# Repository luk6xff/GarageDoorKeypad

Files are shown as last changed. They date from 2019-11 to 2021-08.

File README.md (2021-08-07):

# GarageDoorKeypad

Keypad and Node applications based on STM32F051R8TX uC. Communication between them is done with ISM NRF24L01+ radio modules.

## HARDWARE
* Microcontroller: STM32F051R8TX
* Radio: NRF24L01+
HW schematics for both Keypad and Node available [here](docs/schematics).

## BUILD INSTRUCTIONS
* `STM32CubeIDE ver.1.3.0` with `STM32Cube FW_L0 V1.11.2` is used for development: https://www.st.com/en/development-tools/stm32cubeide.html
* STM32Cube FW_L0 V1.11.2
* Before a first build, please change all the paths `/home/luk6xff/Projects/GarageDoorKeypad/keypad/` and `/home/luk6xff/Projects/GarageDoorKeypad/node/` in files: `.cproject` , `.mxproject` , `.project` for both projects.
* Press `Build Release` button (hammer icon) in IDE to compile a project.
* Press `Run` button (play icon) in IDE to flash a uC.

## Some pics

* Node:
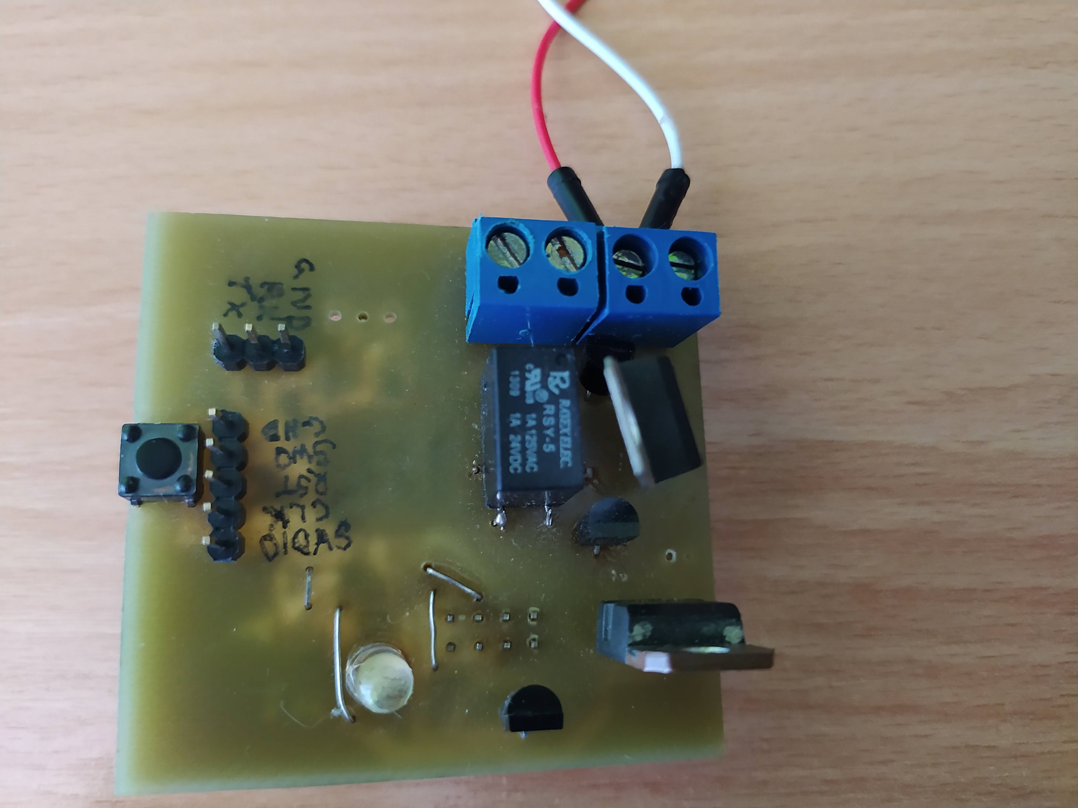
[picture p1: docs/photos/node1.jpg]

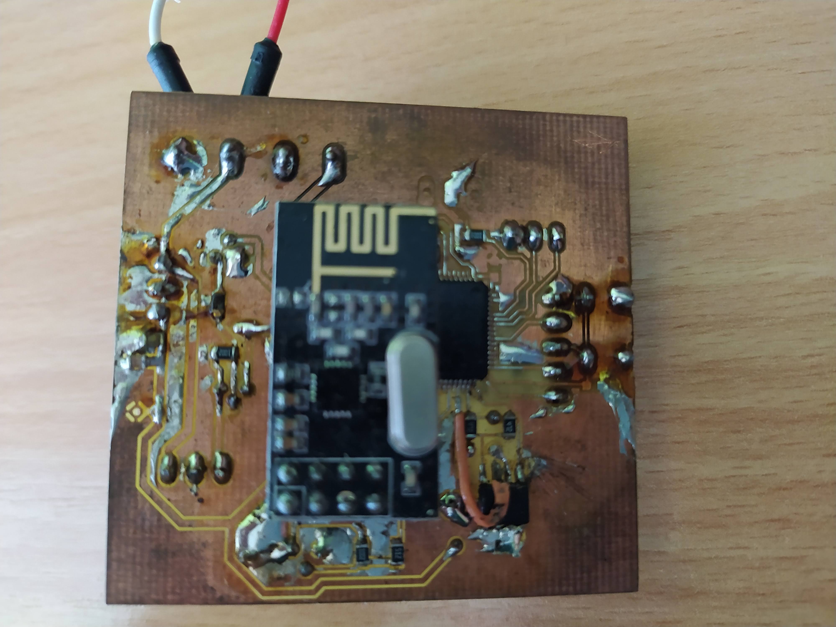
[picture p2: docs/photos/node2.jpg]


* Keypad:
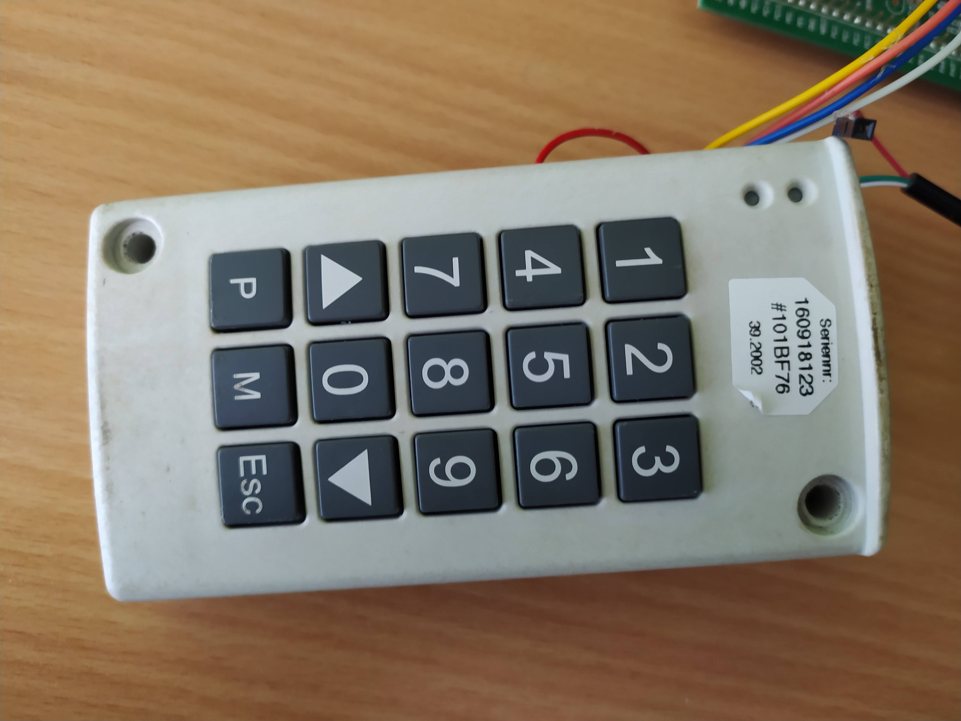
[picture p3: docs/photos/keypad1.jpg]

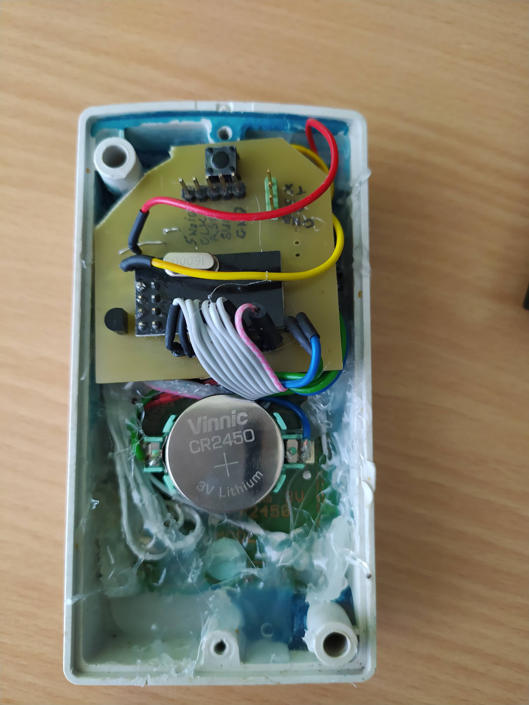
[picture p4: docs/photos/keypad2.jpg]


* Connections:
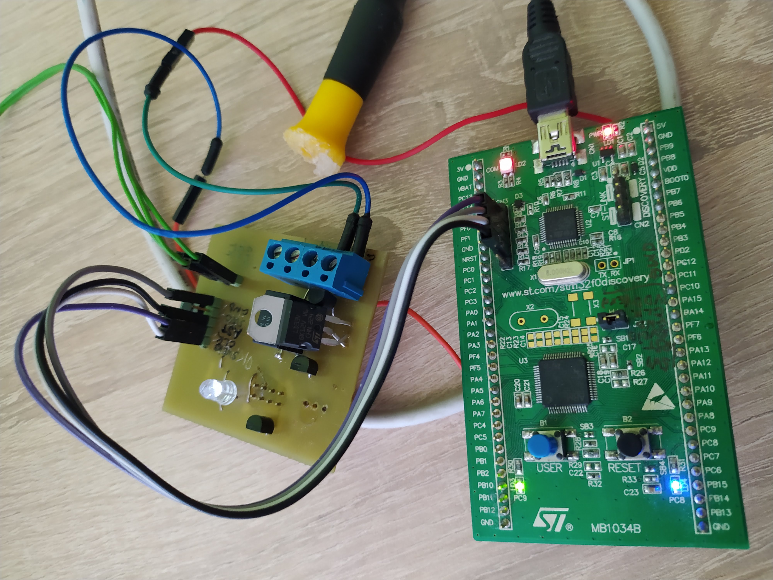
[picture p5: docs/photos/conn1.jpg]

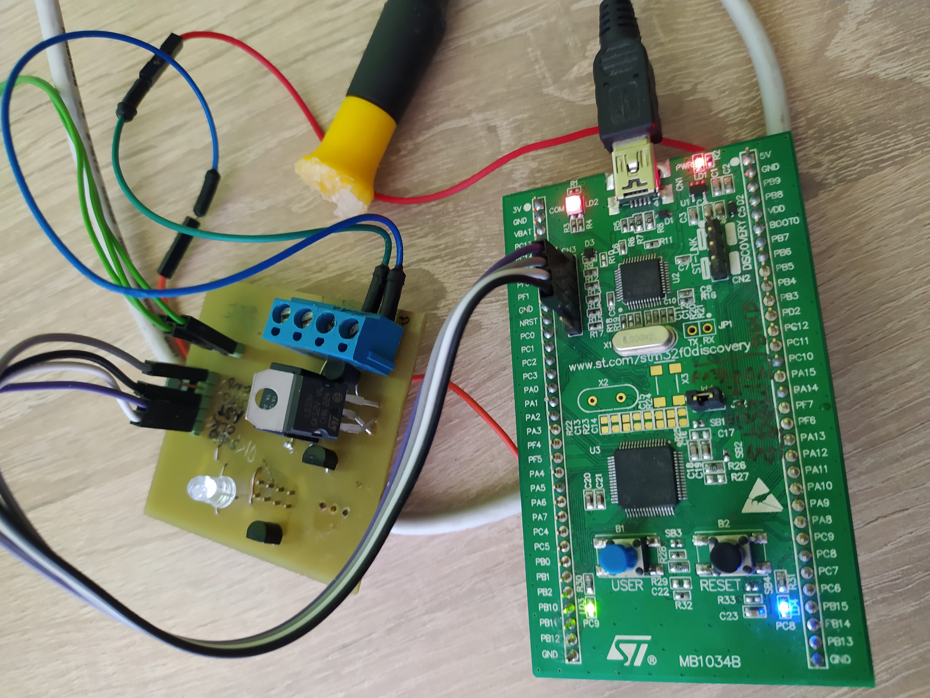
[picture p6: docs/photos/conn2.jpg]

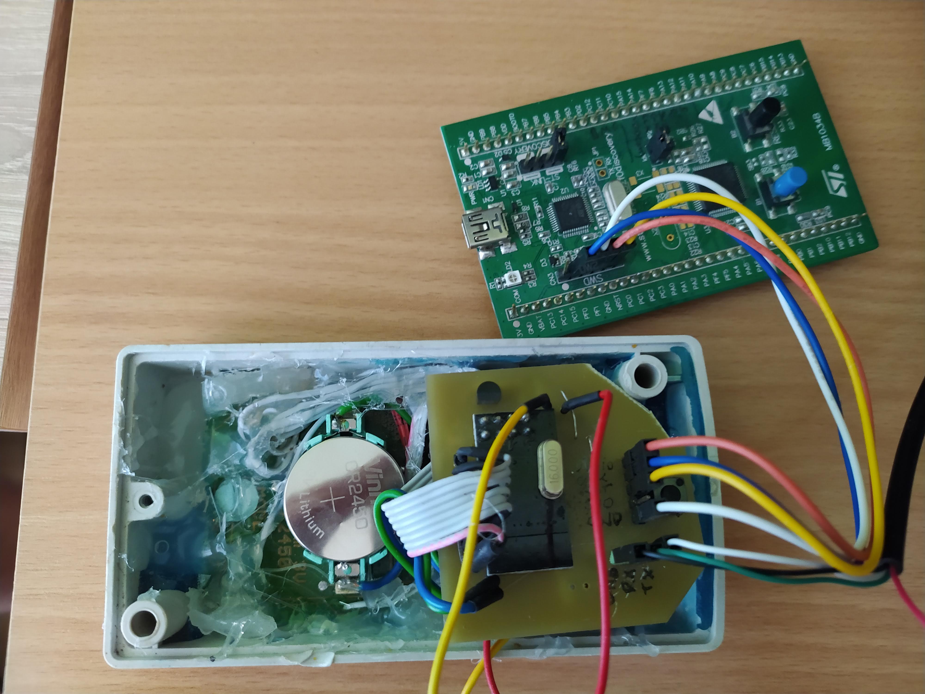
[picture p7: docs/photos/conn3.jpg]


## FAQ
1. To flash SW from CLI:
```sh
~/Tools/STM32/STM32CubeProgrammer/bin/STM32_Programmer_CLI -c port=SWD reset=Hwrst -d ~/Projects/GarageDoorKeypad/.pio/build/disco_f051r8/firmware.elf
```

2. Erase all memory:
```sh
 ~/Tools/STM32/STM32CubeProgrammer/bin/STM32_Programmer_CLI -c port=SWD -e all
```

3. Datasheets to be found [here](docs/datasheets).

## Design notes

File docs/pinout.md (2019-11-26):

# GarageDoorKeypad project pinout
|**uc STM32F051R8T6** |**Peripherals** |
| --- | --- |
| PIN NAME | PIN NAME |
|**_Keypad:_** |
| PA0 | _A_(1,2,3,6) |
| PA1 | _B_(9,4,5,8) |
| PA2 | _C_(0,<,7,>) |
| PA3 | _D_(P,M,ESC) |
| PA4 | _E_(1,9,0,P) |
| PA5 | _F_(3,5,7,ESC) |
| PA6 | _G_(2,4,<,M) |
| PA7 | _H_(6,8,>) |
|**_nRF24L01+:** |
| TR1 (PNP-EMITER) | _GND |
| VCC (3,3V) | VCC |
| PC6 | CE |
| PB12(SPI2_NSS) | CSN |
| PB13(SPI2_SCK) | SCK |
| PB15(SPI2_MOSI) | MOSI|
| PB14(SPI2_MISO) | MISO |
| PC7 | IRQ |
|**_AT24C64D_** |
| GND | A0 |
| GND | A1|
| GND |A2|
| GND |GND |
| PF7(I2C2_SDA)-PullUp 4,7kOhm |SDA |
| PF6(I2C2_SCL)-PullUp 4,7kOhm |SCL|
| PA12-(VCC-disable,GND-enable) |WP |
| VCC (3,3V) |VCC | 
|**_LEDS_** |
| PA11 |GREEN|
| PA10 |RED|
|**_DEBUG_UART_** |
| PB6(USART1_TX) |GOLDPIN_1| 
| PB7(USART1_RX) |GOLDPIN_2|
| GND | GOLDPIN_3 |
|**_ST_LINK_** |
| PA13(SWDIO) |GOLDPIN_1|
| PA14(SWCLK)  |GOLDPIN_2| 
| NRST(ACTIVE_LOW,PullUp-3V) |GOLDPIN_3| 
| PB3 (SWO) |NC|
| GND  |GOLDPIN_5|
|**_POWER_SUPPLY_** |
| 13,1,32,64 (VDDA,VBAT,VDD,VDD) | VCC(3,3)|
| 12,31,63 (VSSA,VSS,VSS) |GND |
|**_TRANSISTORS_** |
|PC8 | TR1 |
|PC9 – FOR RECEIVER ONLY! | _TR2_ |
|  | |
| | | | |

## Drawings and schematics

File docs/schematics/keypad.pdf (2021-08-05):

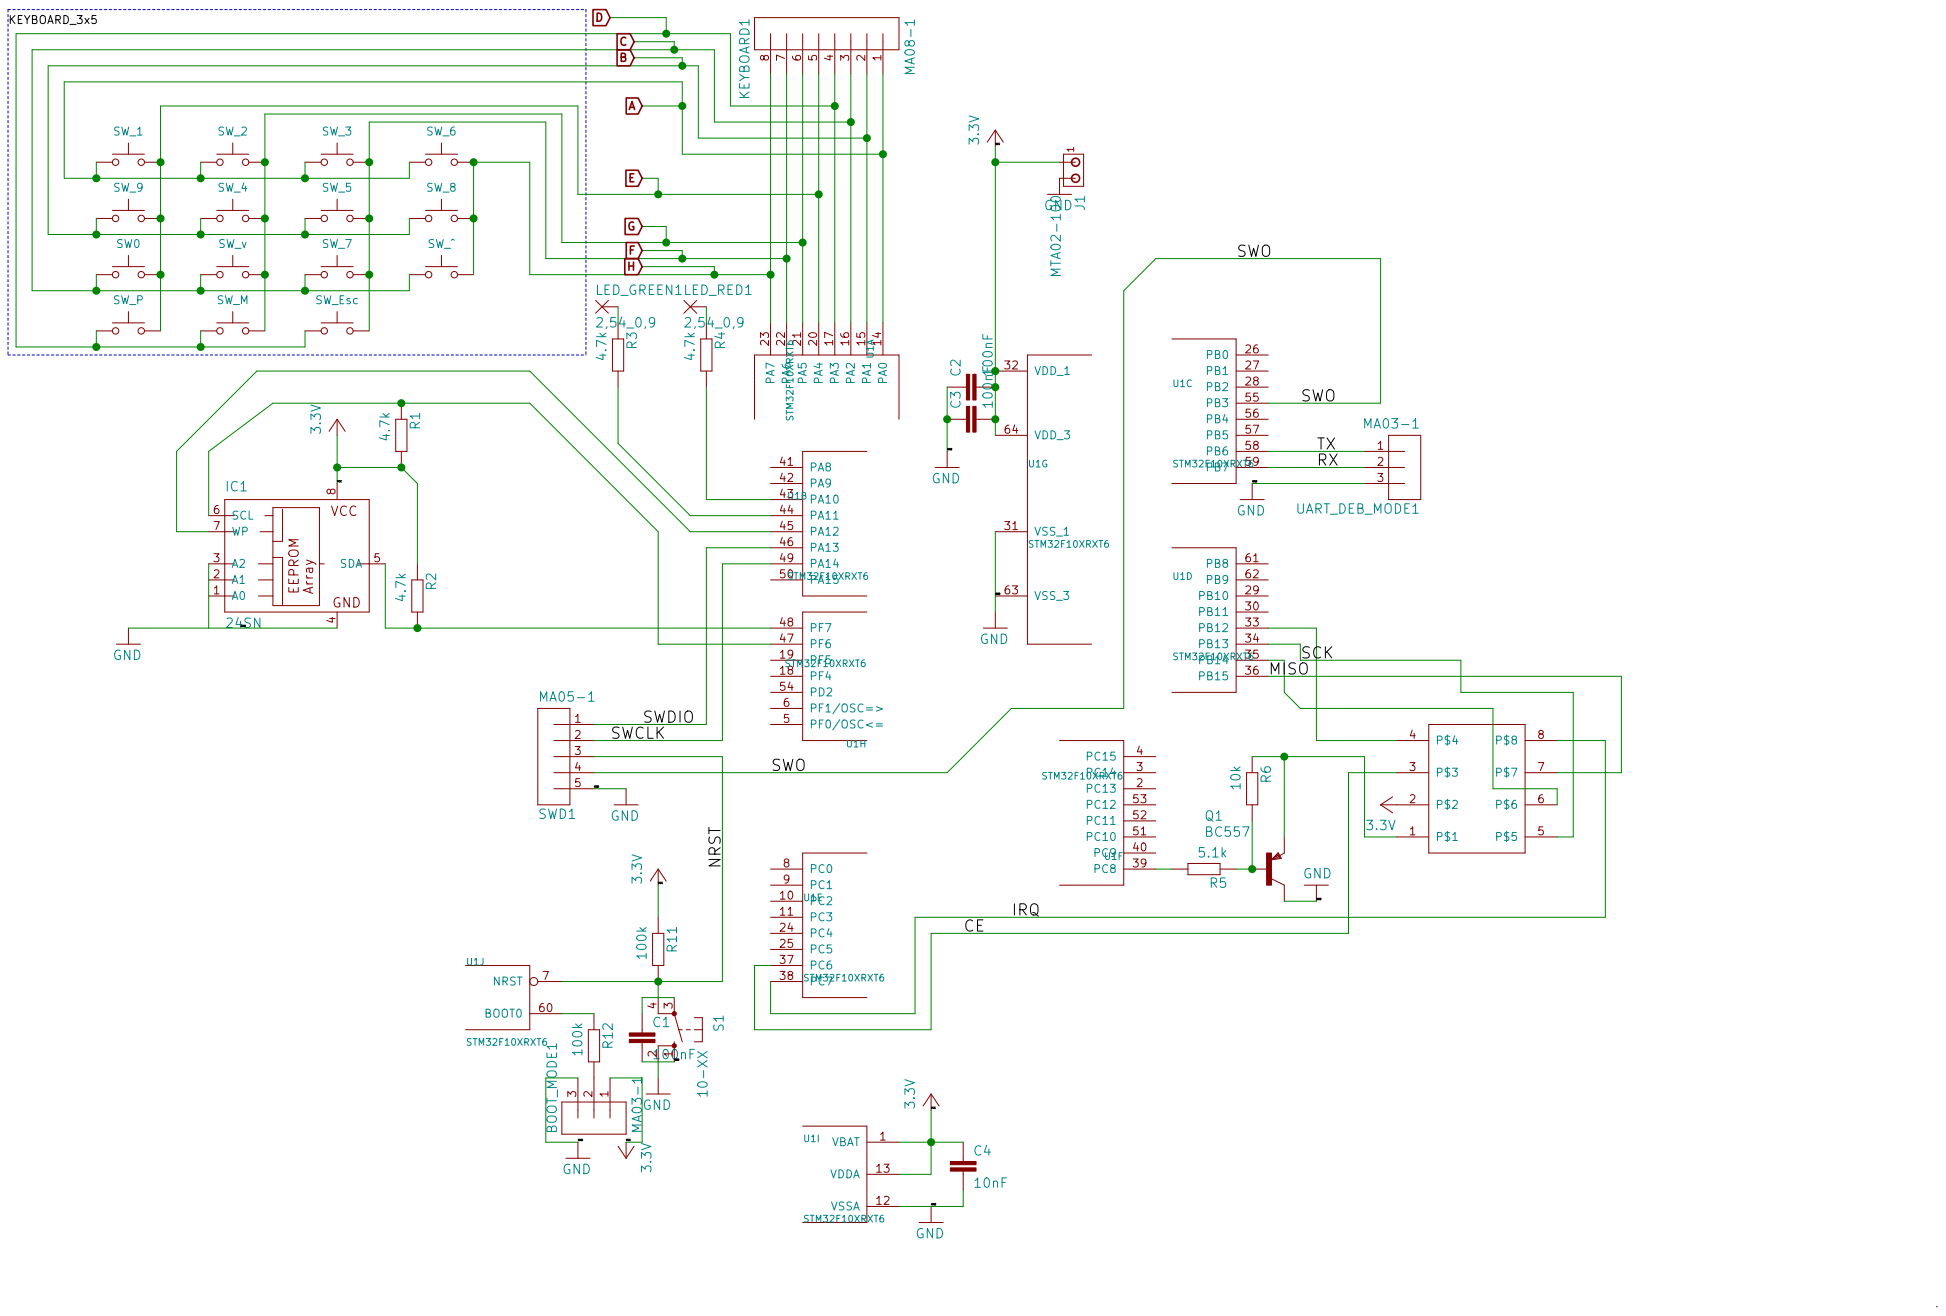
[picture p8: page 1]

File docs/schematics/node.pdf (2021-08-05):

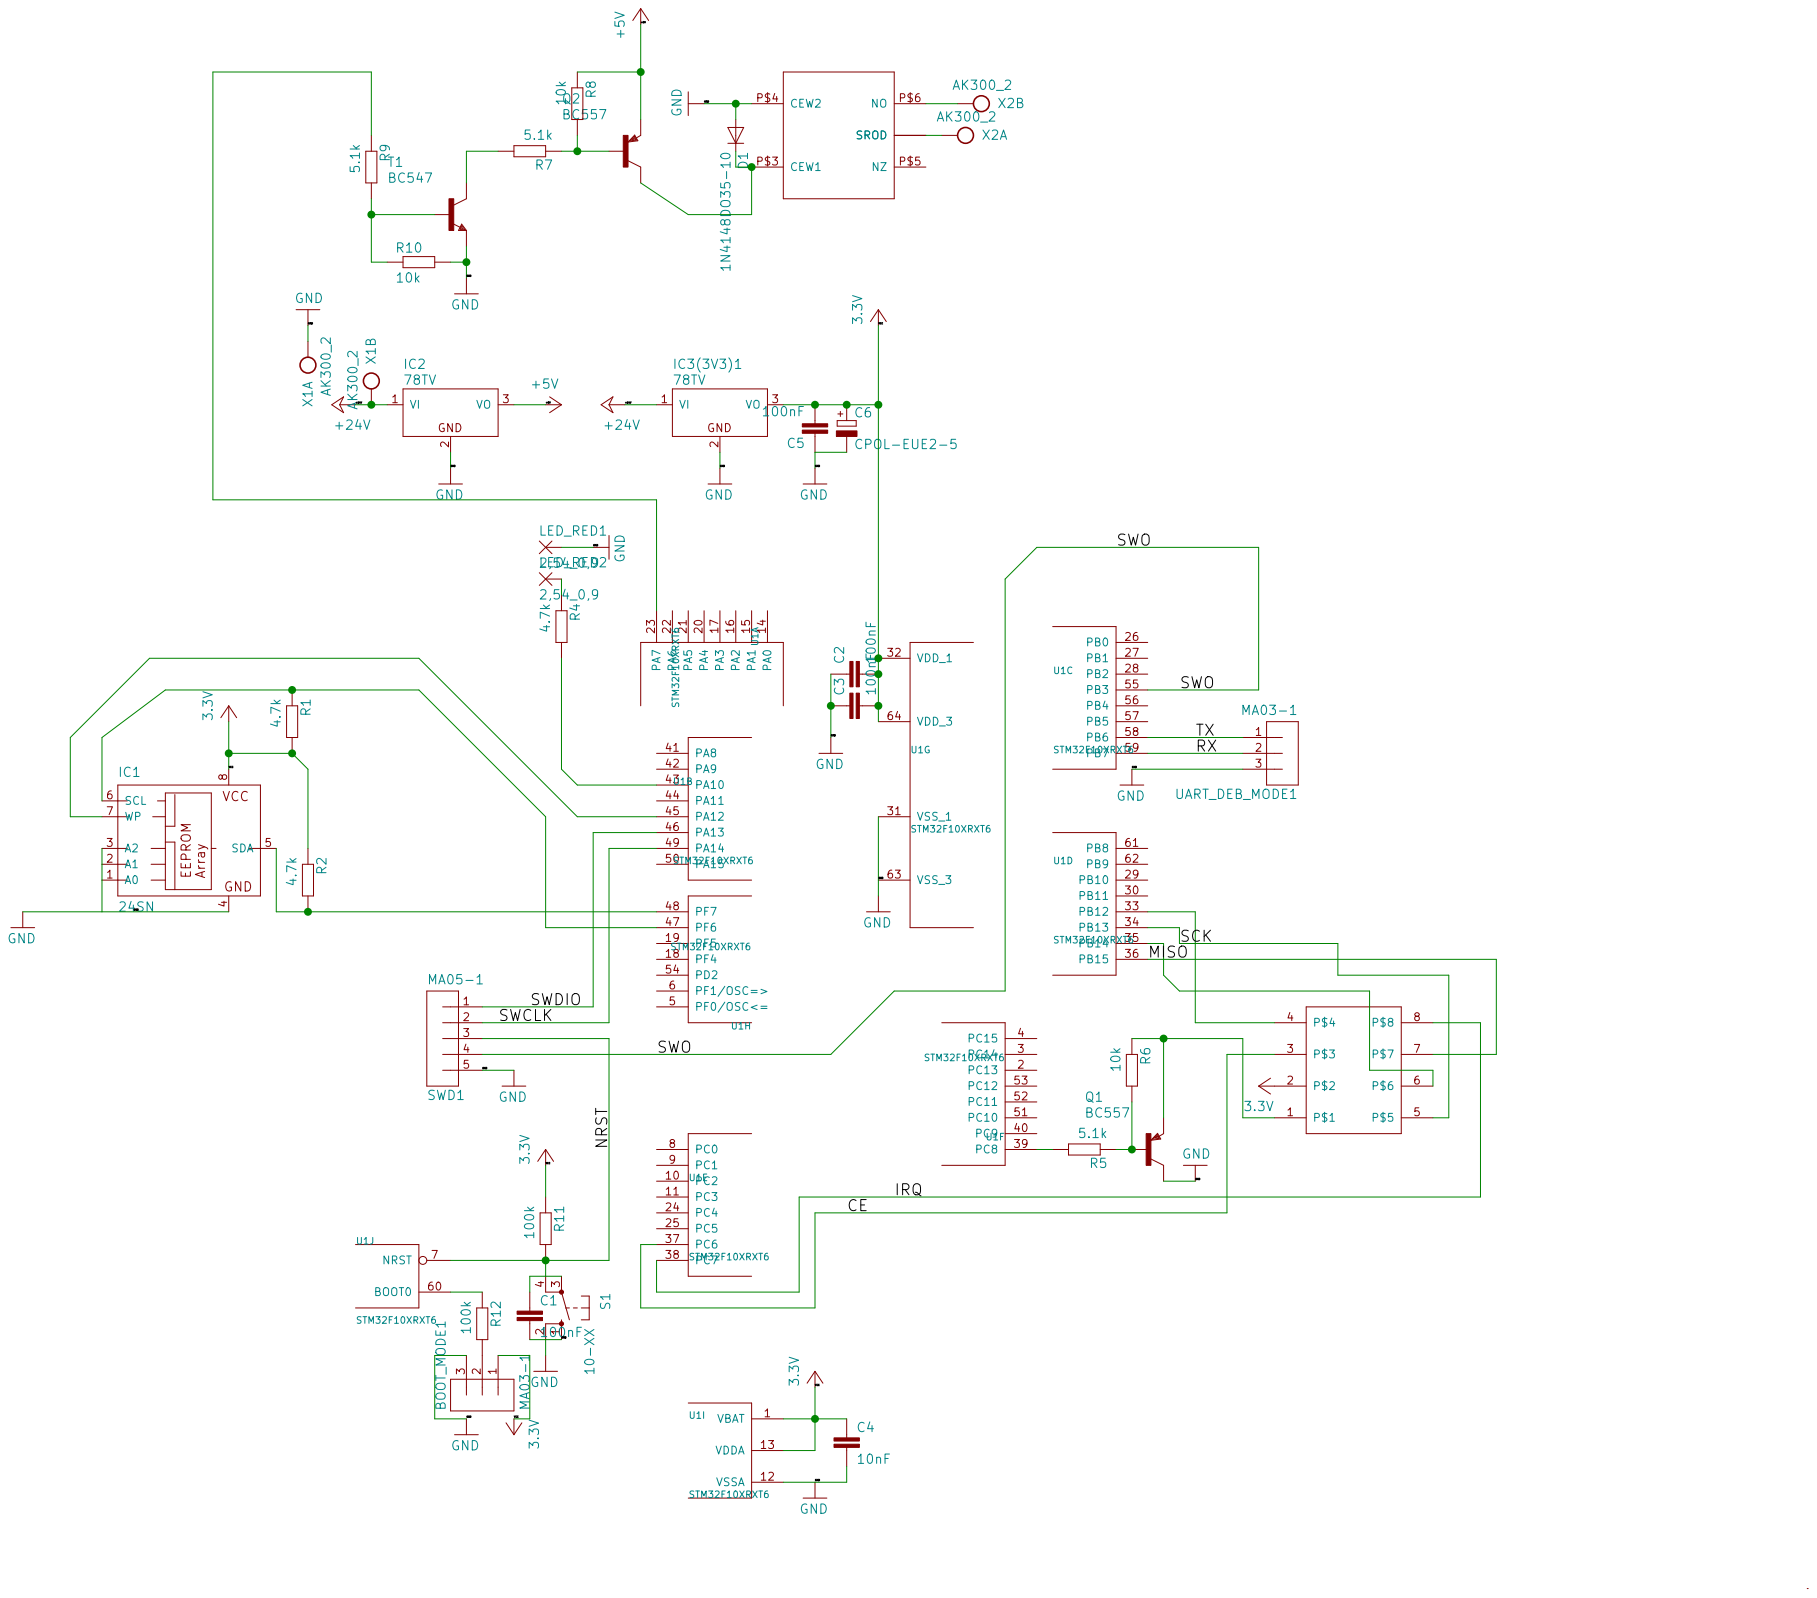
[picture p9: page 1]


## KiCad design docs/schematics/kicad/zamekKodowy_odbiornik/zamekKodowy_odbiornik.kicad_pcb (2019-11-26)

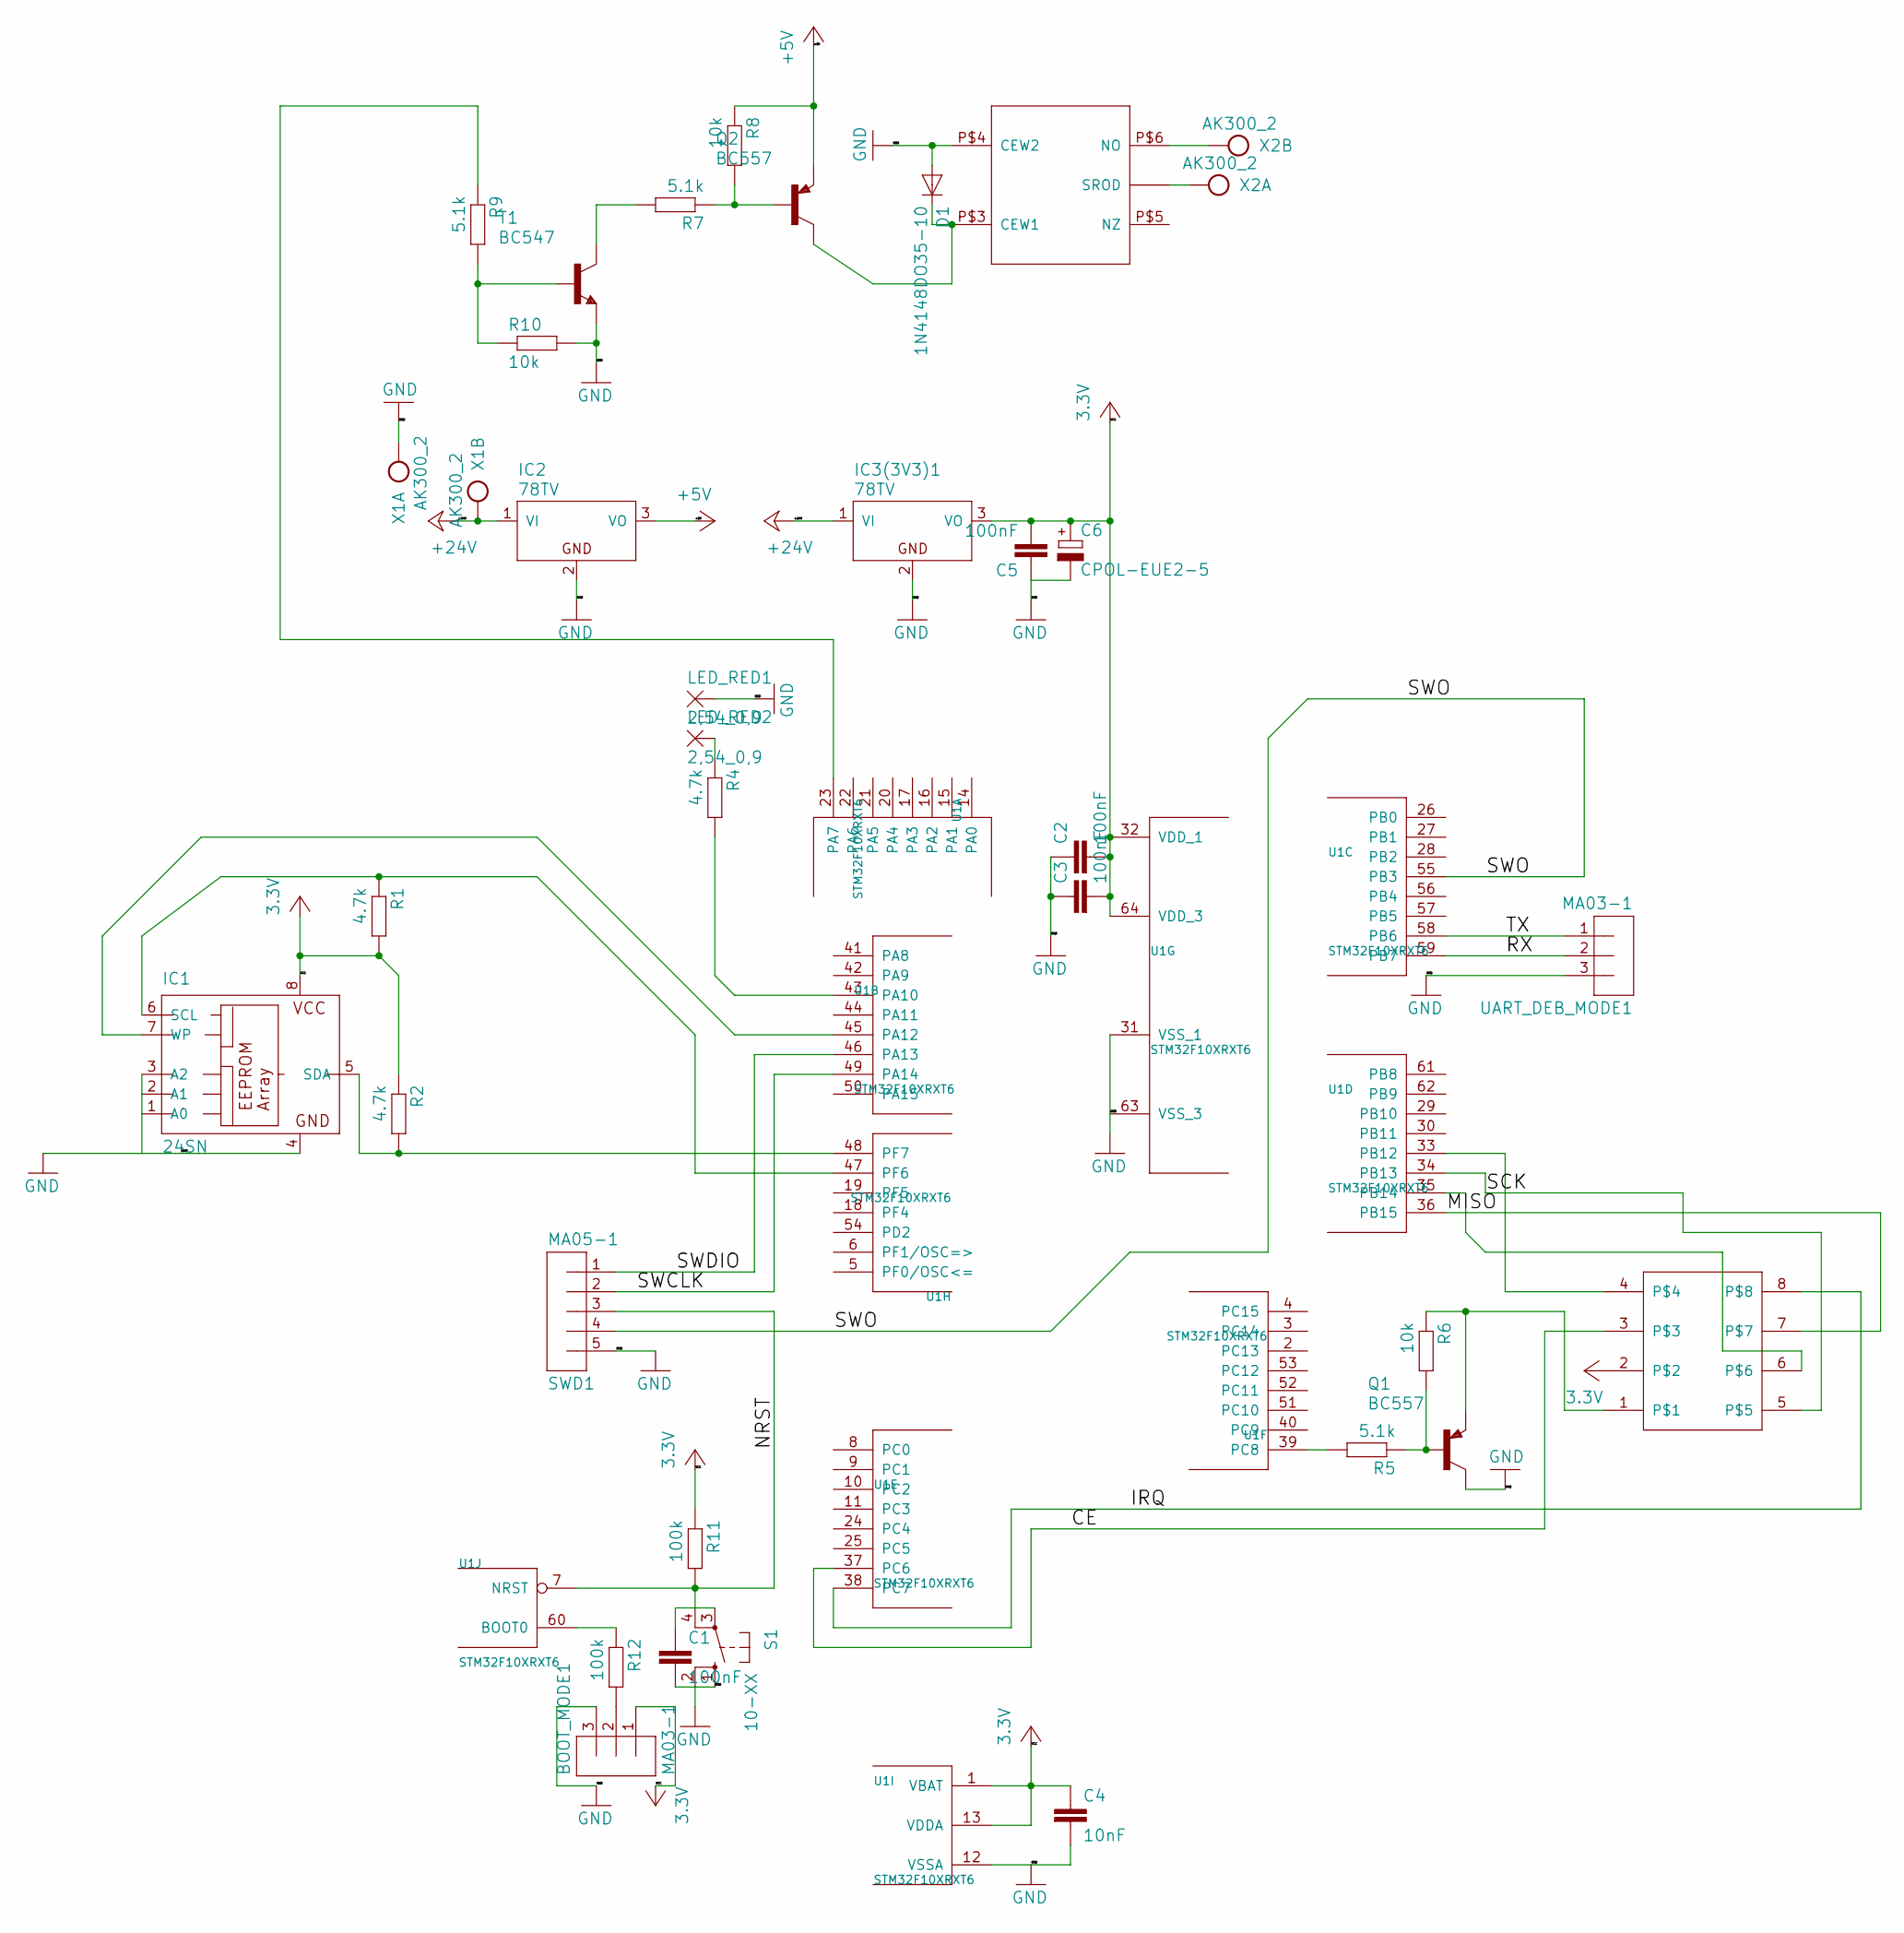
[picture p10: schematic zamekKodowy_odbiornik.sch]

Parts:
BOOT_MODE1: MA03-1
C1, C2, C3, C5: 100nF; C0603
C4: 10nF; C0603
C6: CPOL-EUE2-5; E2-5
CON1: CON10
D1: 1N4148DO35-10; DO35-10
IC1: 24SN; SO-08
IC2, IC3(3V3)1: 78TV; TO220V
LED_RED1, LED_RED2: 2,54_0,9
Q1, Q2: BC557; TO92
R1, R2, R4: 4.7k; R0603
R5, R7, R9: 5.1k; R0603
R6, R8, R10: 10k; R0603
R11, R12: 100k; R0603
S1: 10-XX; B3F-10XX
SWD1: MA05-1
T1: BC547; TO92
U1: STM32F10XRXT6; TQFP64
U$1: PRZEKAZ; FPR
UART_DEB_MODE1: MA03-1
X1, X2: AK300_2

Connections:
+5V: IC2.3 (VO), Q2.1 (E), R8.1
+24V: IC2.1 (VI), IC3(3V3)1.1 (VI), X1.2
/CE: CON1.3, U1.37 (PC6)
/IRQ: CON1.8, U1.38 (PC7)
/MISO: CON1.7, U1.36 (PB15)
/NRST: C1.1, R11.2, S1.3, S1.4 (P1), SWD1.3, U1.7 (NRST)
/RX: U1.59 (PB7), UART_DEB_MODE1.2
/SCK: CON1.5, U1.34 (PB13)
/SWCLK: SWD1.2, U1.49 (PA14)
/SWDIO: SWD1.1, U1.46 (PA13)
/SWO: SWD1.4, U1.55 (PB3)
/TX: U1.58 (PB6), UART_DEB_MODE1.1
GND: BOOT_MODE1.3, C1.2, C2.1, C3.1, C4.2, C5.1, C6.-, D1.A, IC1.1 (A0), IC1.2 (A1), IC1.3 (A2), IC1.4 (GND), IC2.2 (GND), IC3(3V3)1.2 (GND), LED_RED1.1, Q1.3 (C), R10.2, S1.1 (S), S1.2 (S1), SWD1.5, T1.1 (E), U1.12 (VSSA), U1.31 (VSS_1), U1.63 (VSS_3), U$1.P$4 (CEW2), UART_DEB_MODE1.3, X1.1
unnamed: BOOT_MODE1.2, R12.2
unnamed: CON1.1, Q1.1 (E), R6.1
unnamed: CON1.4, U1.33 (PB12)
unnamed: CON1.6, U1.35 (PB14)
unnamed: D1.C, Q2.3 (C), U$1.P$3 (CEW1)
unnamed: IC1.5 (SDA), R2.2, U1.48 (PF7)
unnamed: IC1.6 (SCL), R1.1, U1.47 (PF6)
unnamed: IC1.7 (WP), U1.45 (PA12)
unnamed: LED_RED2.1, R4.1
unnamed: Q1.2 (B), R5.1, R6.2
unnamed: Q2.2 (B), R7.1, R8.2
unnamed: R4.2, U1.43 (PA10)
unnamed: R5.2, U1.39 (PC8)
unnamed: R7.2, T1.3 (C)
unnamed: R9.1, U1.23 (PA7)
unnamed: R9.2, R10.1, T1.2 (B)
unnamed: R12.1, U1.60 (BOOT0)
unnamed: U$1.P$1 (SROD), U$1.P$2 (SROD), X2.1
unnamed: U$1.P$6 (NO), X2.2
VCC: BOOT_MODE1.1, C2.2, C3.2, C4.1, C5.2, C6.+, CON1.2, IC1.8 (VCC), IC3(3V3)1.3 (VO), R1.2, R2.1, R11.1, U1.1 (VBAT), U1.13 (VDDA), U1.32 (VDD_1), U1.64 (VDD_3)

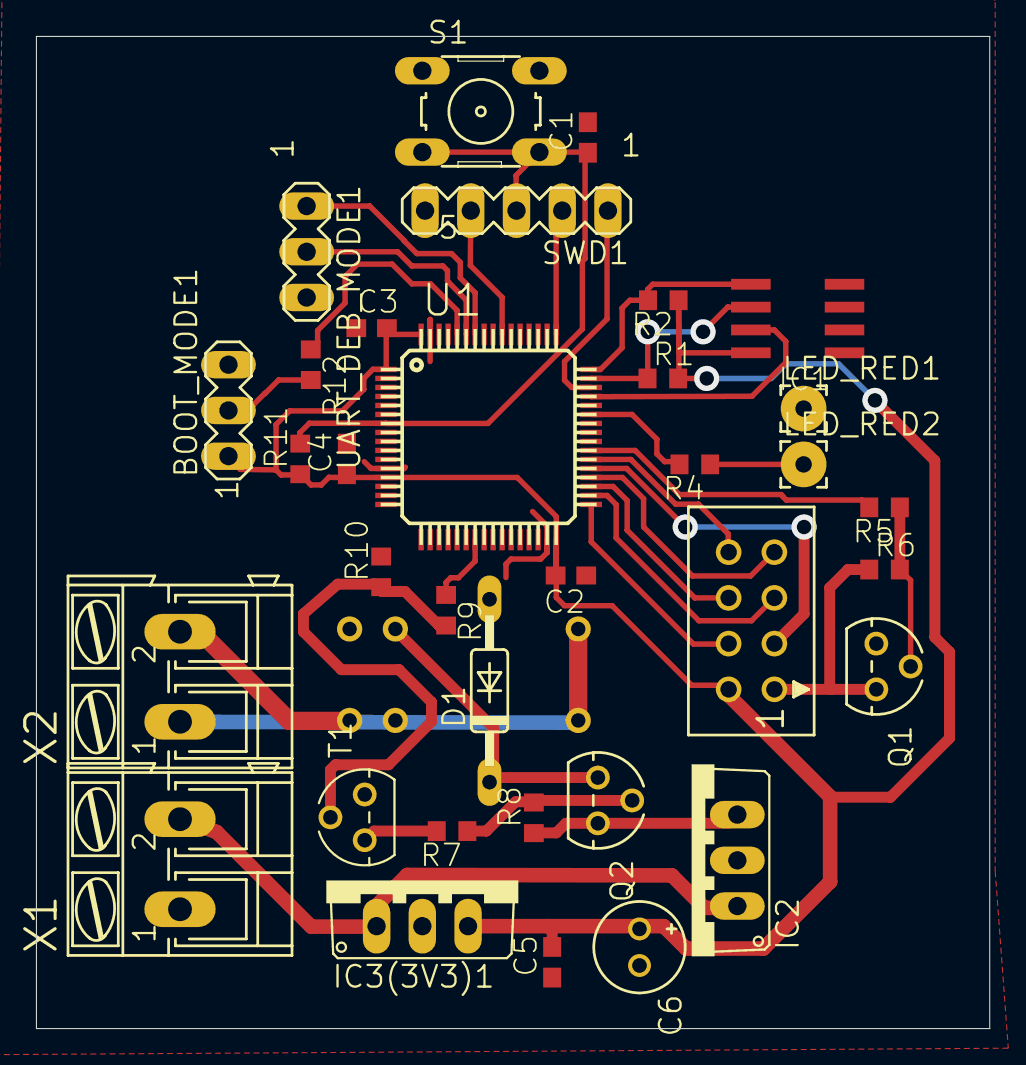
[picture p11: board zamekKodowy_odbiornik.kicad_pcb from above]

Board: 2 copper layers, 53.0 x 55.1 mm, 35 parts (0 on the bottom side), 33 nets.

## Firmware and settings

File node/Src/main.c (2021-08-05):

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

/* Includes ------------------------------------------------------------------*/
#include "main.h"

/* USER CODE BEGIN Includes */
#include "App/app.h"
#include "Utils/utils.h"
#include <stdio.h>
/* USER CODE END Includes */

I2C_HandleTypeDef hi2c2;

IWDG_HandleTypeDef hiwdg;

SPI_HandleTypeDef hspi2;

TIM_HandleTypeDef htim3;

UART_HandleTypeDef huart1;

/* USER CODE BEGIN PV */
#ifdef __GNUC__
/* With GCC, small printf (option LD Linker->Libraries->Small printf
   set to 'Yes') calls __io_putchar() */
#define PUTCHAR_PROTOTYPE int __io_putchar(int ch)
#else
#define PUTCHAR_PROTOTYPE int fputc(int ch, FILE *f)
#endif /* __GNUC__ */
// Retargets the C library printf function to the UART.
PUTCHAR_PROTOTYPE
{
  /* Place your implementation of fputc here */
  /* e.g. write a character to the USART2 and Loop until the end of transmission */
  HAL_UART_Transmit(&huart1, (uint8_t *)&ch, 1, 0xFFFF);

  return ch;
}
/* USER CODE END PV */

void SystemClock_Config(void);
static void MX_GPIO_Init(void);
static void MX_I2C2_Init(void);
static void MX_USART1_UART_Init(void);
static void MX_SPI2_Init(void);
static void MX_TIM3_Init(void);
static void MX_IWDG_Init(void);
/**
  * @brief  The application entry point.
  * @retval int
  */
int main(void)
{
  /* MCU Configuration--------------------------------------------------------*/

  /* Reset of all peripherals, Initializes the Flash interface and the Systick. */
  HAL_Init();

  /* Configure the system clock */
  SystemClock_Config();

  /* USER CODE BEGIN SysInit */
  /**
   * @brief IWDG computation
   * 		Based on: https://controllerstech.com/iwdg-and-wwdg-in-stm32/
   *
   * 	t_iwdg = t_lsi x 4 x 2^PR x (RL+1)
   * 	where: t_lsi = 1 / 32000 (31.25us)
   *
   * 	I need: t_iwdg = 10[s] = 10000[ms]
   * 	Prescaler = 128 so PR = 5
   *	RL = ((t_iwdg x 32000) / ((4 x 2^PR) x 1000)) - 1
   *	RL = ((10000 x 32000) / ((4 x 2^5) x 1000)) - 1
   *	RL = 2500
   *	IWDG down-counter reload value = 2500
   *
   */
  /* USER CODE END SysInit */

  /* Initialize all configured peripherals */
  MX_GPIO_Init();
  MX_I2C2_Init();
  MX_USART1_UART_Init();
  MX_SPI2_Init();
  MX_TIM3_Init();
  MX_IWDG_Init();
  /* USER CODE BEGIN 2 */
  printf("\r\n\r\n\r\n>>> Hello from Garage Door Keypad NODE <<< by luk6xff-2021\r\n");
  printf(">>> Build TIME:%s, DATE:%s\r\n", __TIME__, __DATE__);
  // Scan for I2C devices
  //i2c_scanner();
  // App initialization
  app_init();
  /* USER CODE END 2 */

  /* Infinite loop */
  /* USER CODE BEGIN WHILE */

  while (1)
  {

	app_run();
    /* USER CODE END WHILE */

    /* USER CODE BEGIN 3 */
  }
  /* USER CODE END 3 */
}

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


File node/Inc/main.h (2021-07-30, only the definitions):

#define prescalerValue 7999
#define RELAY_Pin GPIO_PIN_7
#define RELAY_GPIO_Port GPIOA
#define NRF24L01_CSN_Pin GPIO_PIN_12
#define NRF24L01_CSN_GPIO_Port GPIOB
#define NRF24L01_SCK_Pin GPIO_PIN_13
#define NRF24L01_SCK_GPIO_Port GPIOB
#define NRF24L01_MISO_Pin GPIO_PIN_14
#define NRF24L01_MISO_GPIO_Port GPIOB
#define NRF24L01_MOSI_Pin GPIO_PIN_15
#define NRF24L01_MOSI_GPIO_Port GPIOB
#define NRF24L01_CE_Pin GPIO_PIN_6
#define NRF24L01_CE_GPIO_Port GPIOC
#define NRF24L01_IRQ_Pin GPIO_PIN_7
#define NRF24L01_IRQ_GPIO_Port GPIOC
#define TR1_Pin GPIO_PIN_8
#define TR1_GPIO_Port GPIOC
#define TR2_Pin GPIO_PIN_9
#define TR2_GPIO_Port GPIOC
#define LED_RED_Pin GPIO_PIN_10
#define LED_RED_GPIO_Port GPIOA
#define AT24Cx_WP_Pin GPIO_PIN_12
#define AT24Cx_WP_GPIO_Port GPIOA
#define AT24Cx_SCL_Pin GPIO_PIN_6
#define AT24Cx_SCL_GPIO_Port GPIOF
#define AT24Cx_SDA_Pin GPIO_PIN_7
#define AT24Cx_SDA_GPIO_Port GPIOF

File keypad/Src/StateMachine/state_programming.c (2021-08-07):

/*
 * state_processing.c
 *
 *  Created on: Jul 22, 2021
 *      Author: luk6xff
 */

#include "state_programming.h"
#include "states_common.h"
#include "Storage/eeprom.h"
#include "Radio/radio.h"
#include "../KEYPAD_3x5/leds.h"
#include "main.h"
#include <stdio.h>

//------------------------------------------------------------------------------
// Go to sleep counter
static const uint32_t k_go_to_processing_timeout_ms = 20000; // 20[s]
static uint32_t go_to_processing_counter_start_ms = 0;

// Last button pressed timestamp
static uint32_t last_button_pressed_timestamp = 0;

// Radio code
static KeypadButtonPressed current_radio_code[RADIO_CODE_SIZE] = {BUTTON_NONE};
static KeypadButtonPressed current_radio_code_id_button = BUTTON_NONE;
static uint8_t current_radio_code_idx = 0;

//------------------------------------------------------------------------------
static void clear_radio_code()
{
	//printf("RADIO code clearing\r\n");
	current_radio_code_id_button = BUTTON_NONE;
	memset(current_radio_code, BUTTON_NONE, sizeof(current_radio_code));
	current_radio_code_idx = 0;
	last_button_pressed_timestamp = 0;
}

//------------------------------------------------------------------------------
static uint8_t button_id_to_radio_config_id(KeypadButtonPressed btn)
{
	uint8_t radio_id = 0xFF;

	switch (btn)
	{
		case BUTTON_0:
			radio_id = 0;
			break;
		case BUTTON_1:
			radio_id = 1;
			break;
		case BUTTON_2:
			radio_id = 2;
			break;
		case BUTTON_3:
			radio_id = 3;
			break;
		case BUTTON_4:
			radio_id = 4;
			break;
		case BUTTON_5:
			radio_id = 5;
			break;
		case BUTTON_6:
			radio_id = 6;
			break;
		case BUTTON_7:
			radio_id = 7;
			break;
		case BUTTON_8:
			radio_id = 8;
			break;
		case BUTTON_9:
			radio_id = 9;
			break;
	}

	return radio_id;
}

//------------------------------------------------------------------------------
void state_programming(SmCtx *sm)
{
	// In programming state, keep LED_RED light on;
	led_enable(LED_RED);

	if (sm->last_pressed_btn == BUTTON_NONE)
	{
		if (go_to_processing_counter_start_ms == 0)
		{
			go_to_processing_counter_start_ms = HAL_GetTick();
		}

		if ((HAL_GetTick() - go_to_processing_counter_start_ms) > k_go_to_processing_timeout_ms)
		{
			go_to_processing_counter_start_ms = 0;
			clear_radio_code();
			sm->current_state = Processing;
			led_disable_all();
			printf("< processing >\r\n");
		}
	}
	else  // if (sm->last_pressed_btn != BUTTON_NONE)
	{
		// Clear go to processing counter
		go_to_processing_counter_start_ms = 0;
		// Blink LED if valid button pressed
		led_toogle(LED_GREEN, 20);

		const uint32_t timestamp_ms = HAL_GetTick();
		if (last_button_pressed_timestamp > 0 && (timestamp_ms - last_button_pressed_timestamp) > k_max_time_between_consecutive_btns_ms)
		{
			printf("programming - RADIO code timeout expired, jump to Processing-> timestamp_ms:%lu, last_button_pressed_timestamp:%lu\r\n", timestamp_ms, last_button_pressed_timestamp);
			clear_radio_code();
			sm->current_state = Processing;
			led_disable_all();
			printf("< processing >\r\n");
		}
		else
		{
			if (current_radio_code_id_button == BUTTON_NONE)
			{
				current_radio_code_id_button = sm->last_pressed_btn;
				last_button_pressed_timestamp = timestamp_ms;
			}

			else if (sm->last_pressed_btn != BUTTON_M && sm->last_pressed_btn != BUTTON_ARROW_UP)
			{
				current_radio_code[current_radio_code_idx++] = sm->last_pressed_btn;
				last_button_pressed_timestamp = timestamp_ms;
			}

			else if (sm->last_pressed_btn == BUTTON_M || sm->last_pressed_btn == BUTTON_ARROW_UP)
			{
				// Check if provided code is full and valid
				if (verify_radio_code(current_radio_code, current_radio_code_idx))
				{
					printf("programming - verify_radio_code success\r\n");
					// Check if new code already exists, if so, let's fail
					if (eeprom_check_if_radio_code_exists(current_radio_code) == -1)
					{
						radio_msg msg;
						msg.msg_type = MSG_CODE_PROGRAM_REQ;
						msg.radio_cfg.id = button_id_to_radio_config_id(current_radio_code_id_button);
						memcpy(msg.radio_cfg.code, current_radio_code, sizeof(msg.radio_cfg.code));

						/**
						 * @note If save was done by BUTTON_M, you have to check if code id already exist before sending message.
						 * If you want to skip this check run storing by pressing BUTTON_ARROW_UP
						 */
						if (sm->last_pressed_btn == BUTTON_M)
						{
							if (eeprom_check_if_radio_code_id_exists(msg.radio_cfg.id))
							{
								printf("eeprom - There is already a radio_code id:%lu registered. Stopping registering a new one!\r\nUse a BUTTON_ARROW_UP to overwrite the old one\r\n", msg.radio_cfg.id);
								led_toogle_loop(LED_RED, k_led_toogle_time_ms, 4);
								goto exit;
							}
						}

						printf("programming - Sending a new radio msg: MSG_CODE_PROGRAM_REQ...\r\n");
						radio_send_msg(&msg);
						led_toogle_loop(LED_GREEN, k_led_toogle_time_ms, 1);
						// Wait for a response from the NODE
						const uint32_t start_ms = HAL_GetTick();
						const uint32_t timeout_ms = k_wait_for_response_from_node_timeout_ms;
						bool response_received = false;
						while ((HAL_GetTick() - start_ms) < timeout_ms)
						{
							kick_watchdog();
							if (radio_read_msg(&msg))
							{
								printf("programming - Radio response received! MSG_TYPE:%lu\r\n", msg.msg_type);
								if (msg.msg_type == MSG_CODE_PROGRAM_RES)
								{
									response_received = true;
									break;
								}
							}
						}
						// Any response from the NODE received
						if (response_received)
						{
							printf("programming - Radio response MSG_CODE_PROGRAM_RES successfully received, storing new code!\r\n");
							if (eeprom_store_new_radio_code(current_radio_code, sizeof(current_radio_code), button_id_to_radio_config_id(current_radio_code_id_button)))
							{
								printf("programming - eeprom_store_new_radio_code success!\r\n");
								led_toogle_loop(LED_GREEN, k_led_toogle_time_ms, 3);
							}
							else
							{
								printf("programming - eeprom_store_new_radio_code failed!\r\n");
								led_toogle_loop(LED_RED, k_led_toogle_time_ms, 4);
							}
						}
						else
						{
							printf("programming- No Radio response MSG_CODE_PROGRAM_RES received during timeout\r\n");
							led_toogle_loop(LED_RED, k_led_toogle_time_ms, 3);
						}
					}
					else
					{
						printf("programming- This radio code already exists! Cannot store it!\r\n");
						led_toogle_loop(LED_RED, k_led_toogle_time_ms, 5);
					}
				}
				else
				{
					printf("programming - verify_radio_code failed!\r\n");
					led_toogle_loop(LED_RED, k_led_toogle_time_ms, 2);
				}
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

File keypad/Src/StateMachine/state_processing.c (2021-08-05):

/*
 * state_processing.c
 *
 *  Created on: Jul 22, 2021
 *      Author: luk6xff
 */

#include "state_processing.h"
#include "states_common.h"
#include "Storage/eeprom.h"
#include "Radio/radio.h"
#include "../KEYPAD_3x5/leds.h"
#include "main.h"
#include <stdio.h>


//------------------------------------------------------------------------------
// Go to sleep counter
static const uint32_t k_go_to_sleep_timeout_ms = 20000; // 20[s]
static uint32_t go_to_sleep_counter_start_ms = 0;

// Last button pressed timestamp
static uint32_t last_button_pressed_timestamp = 0;

// Radio code
static KeypadButtonPressed current_radio_code[RADIO_CODE_SIZE] = {BUTTON_NONE};
static uint8_t current_radio_code_idx = 0;

//------------------------------------------------------------------------------
static void clear_radio_code()
{
	//printf("RADIO code clearing\r\n");
	memset(current_radio_code, BUTTON_NONE, sizeof(current_radio_code));
	current_radio_code_idx = 0;
	last_button_pressed_timestamp = 0;
}

//------------------------------------------------------------------------------
void state_processing(SmCtx *sm)
{
	if (sm->last_pressed_btn == BUTTON_NONE)
	{
		if (go_to_sleep_counter_start_ms == 0)
		{
			go_to_sleep_counter_start_ms = HAL_GetTick();
		}

		if ((HAL_GetTick() - go_to_sleep_counter_start_ms) > k_go_to_sleep_timeout_ms)
		{
			go_to_sleep_counter_start_ms = 0;
			clear_radio_code();
			sm->current_state = Sleeping;
			printf("< sleeping >\r\n");
		}
	}
	else  // if (sm->last_pressed_btn != BUTTON_NONE)
	{
		// Clear go to sleeping timer
		go_to_sleep_counter_start_ms = 0;
		// Blink LED if valid button pressed
		led_toogle(LED_GREEN, 20);

		const uint32_t timestamp_ms = HAL_GetTick();
		if (last_button_pressed_timestamp > 0 && (timestamp_ms - last_button_pressed_timestamp) > k_max_time_between_consecutive_btns_ms)
		{
			printf("processing - RADIO code timeout expired-> timestamp_ms:%lu, last_button_pressed_timestamp:%lu\r\n", timestamp_ms, last_button_pressed_timestamp);
			// Clear last provided radio code
			clear_radio_code();
		}
		else
		{
//			printf("RADIO code button pressed:%d\r\n", sm->last_pressed_btn);
//			printf("RADIO code current_radio_code_idx=%d\r\n", current_radio_code_idx);
			current_radio_code[current_radio_code_idx++] = sm->last_pressed_btn;
			last_button_pressed_timestamp = timestamp_ms;
			// Check if provided code is full and valid
			if (verify_radio_code(current_radio_code, current_radio_code_idx))
			{
				const int radio_code_id = eeprom_check_if_radio_code_exists(current_radio_code);
				if (radio_code_id != -1)
				{
					printf("processing - eeprom_check_if_radio_code_exists - true\r\n");
					radio_msg msg;
					msg.msg_type = MSG_CODE_REQ;
					memcpy(&(msg.radio_cfg), &(eeprom_data_get_current()->radio_configs[radio_code_id]), sizeof(msg.radio_cfg));
					printf("processing - Sending a new radio msg: MSG_CODE_REQ...\r\n");
					radio_send_msg(&msg);
					led_toogle_loop(LED_GREEN, k_led_toogle_time_ms, 1);
					// Wait for a response from node
					const uint32_t start_ms = HAL_GetTick();
					const uint32_t timeout_ms = k_wait_for_response_from_node_timeout_ms;
					bool response_received = false;
					while ((HAL_GetTick() - start_ms) < timeout_ms)
					{
						kick_watchdog();
						if (radio_read_msg(&msg))
						{
							printf("processing - Radio response received! MSG_TYPE:%lu\r\n", msg.msg_type);
							if (msg.msg_type == MSG_CODE_RES)
							{
								response_received = true;
								break;
							}
						}
					}

					if (response_received)
					{
						printf("processing - Radio response MSG_CODE_RES successfully received\r\n");
						led_toogle_loop(LED_GREEN, k_led_toogle_time_ms, 3);
					}
					else
					{
						printf("processing - No Radio MSG_CODE_RES response received during timeout\r\n");
						led_toogle_loop(LED_RED, k_led_toogle_time_ms, 3);
					}
				}
				else
				{
					printf("processing - Non existing radio code provided\r\n");
					led_toogle_loop(LED_RED, k_led_toogle_time_ms, 3);
				}
			}

			if (current_radio_code_idx >= RADIO_CODE_SIZE)
			{
				// Check if clear code has been applied
				verify_and_clear_radio_codes(current_radio_code, current_radio_code_idx);
				clear_radio_code();
			}
		}

		// If BUTTON_P, go to programming session.
		if (sm->last_pressed_btn == BUTTON_P)
		{
			// Clear last provided radio code
			clear_radio_code();
			sm->current_state = Programming;
			printf("< programming >\r\n");
		}
		// If BUTTON_ESC, clean all and run again
		else if (sm->last_pressed_btn == BUTTON_ESC)
		{
			// Clear last provided radio code
			clear_radio_code();
			led_toogle_loop(LED_RED, k_led_toogle_time_ms, 3);
		}
	}
}

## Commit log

2019-12-01 Update solution to stm32cube
2019-12-03 SPI for NRF works like a charm
2021-07-22 Keypad button readout finish on falling edge
2021-07-27 AT24cxx driver fix
2021-07-29 msgs req/res flow done
2021-07-30 Fail on storing already existing radio code in memory
    [app.c, eeprom.c, state_programming.c]
2021-07-30 Relay helper
2021-07-30 Led blinking
2021-07-30 Leds toogling modified
2021-08-05 ESC button enabled
2021-08-05 Schematics finally frozen
    [zamekKodowy_nadajnik.sch]
2021-08-07 Fix for btn arrow up storing codes, photos added
    [state_programming.c]

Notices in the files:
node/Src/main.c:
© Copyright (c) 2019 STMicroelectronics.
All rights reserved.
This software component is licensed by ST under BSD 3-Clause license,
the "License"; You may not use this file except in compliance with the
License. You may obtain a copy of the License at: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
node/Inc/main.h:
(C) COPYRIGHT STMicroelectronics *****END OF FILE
